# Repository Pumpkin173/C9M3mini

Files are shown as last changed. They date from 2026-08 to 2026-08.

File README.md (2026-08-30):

# C9M3mini 

C9M3mini is a comprehensive open-source camera project, featuring custom hardware (PCBs), 3D printable enclosures, and a C++ based camera application with UI and WiFi sharing capabilities.

## Project Overview
This repository contains everything you need to build the C9M3mini camera from scratch:
- **Software**: A Qt-based C++ application for album viewing, video HUD display, and WiFi sharing.
- **Hardware**: Gerber files and BOMs for custom PCBs (power board, battery board, keypad, etc.).
- **Mechanical**: 3D models (`.3mf`) for 3D printing the camera enclosure.

## Repository Structure
- `/C9M3mini` - The core C++ camera application source code.
- `/C9M3mini_berger` - Hardware manufacturing files. Includes `.zip` Gerber files for PCB fabrication and `.xlsx` Bill of Materials (BOM).
- `C9M3mini_modle.3mf` - 3D printable model for the camera housing (Bambu Studio compatible).

## Software Features
- **Album Viewer**: View captured photos directly on the device.
- **Video HUD**: Heads-Up Display for real-time video recording and monitoring.
- **WiFi Share & Monitor**: Generate QR codes to connect to a local WiFi hotspot and browse files via SMB. Includes real-time connection and speed monitoring.
- **Autostart Support**: Scripts provided to configure the app to run automatically on boot (optimized for Raspberry Pi).

## Prerequisites & Build Instructions (Software)

### Prerequisites
- CMake (version 3.10 or higher)
- C++ Compiler (GCC, Clang, etc.)
- Qt Framework (for UI components)
- `qrencode` (for generating WiFi sharing QR codes)
- Linux network utilities (`ip`, `iw`) for network monitoring

### Build Steps
1. Clone the repository:
   ```bash
   git clone https://github.com/Pumpkin173/C9M3mini.git
   cd C9M3mini/C9M3mini
2. Build the project using CMake:
   mkdir build && cd build
   cmake ..
   cmake --build .
Autostart Setup
To set up the application to run automatically on startup (e.g., on a Raspberry Pi):
./scripts/setup_autostart.sh
## Authors
[Pumpkin173] (Creator & Hardware/Software Engineer)
antigravity--Gemini (Co-author & Assistant)
## License
This project is licensed under the GNU General Public License v3.0 (GPLv3) - see the 
LICENSE file for details.

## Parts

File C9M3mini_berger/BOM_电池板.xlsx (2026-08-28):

No. | Quantity | Comment | Designator | Footprint | Value | Manufacturer Part | Manufacturer | Supplier Part | Supplier
1 | 2 | 100nF | C13,C14 | C0603 | 100nF | CC0603KRX7R9BB104 | YAGEO(国巨) | C14663 | LCSC
2 | 2 | HJ8205 | Q1,Q2 | SOT-23-6_L2.9-W1.6-P0.95-LS2.8-BR |  | HJ8205 | R+O(宏嘉诚) | C20069150 | LCSC
3 | 2 | 330Ω | R21,R22 | R0603 | 330Ω | 0603WAF3300T5E | UNI-ROYAL(厚声) | C23138 | LCSC
4 | 1 | 2kΩ | R23 | R0603 | 2kΩ | 0603WAF2001T5E | UNI-ROYAL(厚声) | C22975 | LCSC
5 | 1 | KNTC0603/10KF3950 | RNTC0 | R0603 |  | KNTC0603/10KF3950 | KUU | C2892547 | LCSC
6 | 1 | 23E413050 | U1 | SMD_23E413050 |  | 23E413050 | SAMZO(三佐) | C39833033 | LCSC
7 | 1 | HY2120-CB | U12 | SOT-23-6_L2.9-W1.6-P0.95-LS2.8-BR |  | HY2120-CB | HYCON(宏康) | C116509 | LCSC

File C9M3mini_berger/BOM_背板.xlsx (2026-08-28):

No. | Quantity | Comment | Designator | Footprint | Value | Manufacturer Part | Manufacturer | Supplier Part | Supplier
1 | 5 | 10uF | C1,C2,C21,C24,C27 | C1206 | 10uF | CL31A106KAHNNNE | SAMSUNG(三星) | C9807 | LCSC
2 | 10 | 100nF | C3,C4,C10,C11,C12,C13,C15,C20,C25,C26 | C0603 | 100nF | CC0603KRX7R9BB104 | YAGEO(国巨) | C14663 | LCSC
3 | 1 | 10nF | C5 | C0603 | 10nF | 0603B103K500NT | FH(风华) | C57112 | LCSC
4 | 1 | 2.2nF | C6 | C0603 | 2.2nF | 0603B222K500NT | FH(风华) | C1604 | LCSC
5 | 1 | 22pF | C7 | C0603 | 22pF | CL10C220JB8NNNC | SAMSUNG(三星) | C1653 | LCSC
6 | 2 | 47uF | C8,C9 | C1206 | 47uF | CL31A476MPHNNNE | SAMSUNG(三星) | C96123 | LCSC
7 | 1 | 10uF | C14 | C0603 | 10uF | FCC0603X106K100CT | FOJAN(富捷) | C5137565 | LCSC
8 | 1 | 100pF | C23 | C0603 | 100pF | CL10C101JB8NNNC | SAMSUNG(三星) | C14858 | LCSC
9 | 1 | 1uF | C28 | C0805 | 1uF | CL21B105KBFNNNE | SAMSUNG(三星) | C28323 | LCSC
10 | 1 | HC-1.25-2PWT | CN1 | CONN-SMD_2P-P1.25-HC-1.25-2PWT |  | HC-1.25-2PWT | HCTL(华灿天禄) | C2845379 | LCSC
11 | 4 | SS54 | D1,D2,D4,D5 | SMA_L4.3-W2.6-LS5.0-FD |  | SS54 | R+O(宏嘉诚) | C7420369 | LCSC
12 | 1 | SS34 | D3 | SMA_L4.3-W2.6-LS5.2-RD |  | SS34 | MDD(辰达半导体) | C8678 | LCSC
13 | 1 | BSMD1812L-500 | F1 | F1812 |  | BSMD1812L-500 | BHFUSE(佰宏) | C42429411 | LCSC
14 | 1 | FPC-05F-6PH20 | FPC_BACK61 | FPC-SMD_6P-P0.50_XUNPU_FPC-05F-6PH20 |  | FPC-05F-6PH20 | XUNPU(讯普) | C2856796 | LCSC
15 | 1 | AFC01-S16FCA-00 | FPC_FORNT1 | FPC-SMD_P0.50-16P_FGS-XJ-H2.0 |  | AFC01-S16FCA-00 | JS(钜硕电子) | C262665 | LCSC
16 | 1 | AFC01-S10FCA-00 | FPC_TOP1 | FPC-SMD_P0.5-10P_FGS-XJ-H2.0 |  | AFC01-S10FCA-00 | JS(钜硕电子) | C262659 | LCSC
17 | 1 | SLO0520H100MTT | L2 | IND-SMD_L5.4-W5.1 |  | SLO0520H100MTT | Sunltech(顺磁) | C325986 | LCSC
18 | 1 | AFC07-S22ECC-00 | P5 | FPC-SMD_P0.50-22P_LSSJ-H2.0-22P |  | AFC07-S22ECC-00 | JS(钜硕电子) | C11091 | LCSC
19 | 1 | 150kΩ | R1 | R0603 | 150kΩ | FRC0603F1503TS | FOJAN(富捷) | C2906993 | LCSC
20 | 1 | 39kΩ | R2 | R0603 | 39kΩ | 0603WAF3902T5E | UNI-ROYAL(厚声) | C23153 | LCSC
21 | 1 | 37.4kΩ | R3 | R0603 | 37.4kΩ | RMC060337.4K1%N | Tyohm(幸亚电阻) | C325691 | LCSC
22 | 1 | 49.9Ω | R4 | R0603 | 49.9Ω | 0603WAF499JT5E | UNI-ROYAL(厚声) | C23185 | LCSC
23 | 1 | 22kΩ | R5 | R0603 | 22kΩ | 0603WAF2202T5E | UNI-ROYAL(厚声) | C31850 | LCSC
24 | 1 | 3.9kΩ | R6 | R0603 | 3.9kΩ | 0603WAF3901T5E | UNI-ROYAL(厚声) | C23018 | LCSC
25 | 1 | 4.7kΩ | R11 | R0603 | 4.7kΩ | 0603WAF4701T5E | UNI-ROYAL(厚声) | C23162 | LCSC
26 | 1 | 27kΩ | R12 | R0603 | 27kΩ | 0603WAF2702T5E | UNI-ROYAL(厚声) | C22967 | LCSC
27 | 1 | 1kΩ | R13 | R0603 | 1kΩ | 0603WAF1001T5E | UNI-ROYAL(厚声) | C21190 | LCSC
28 | 1 | 50kΩ | R14 | R0603 | 50kΩ | RT0603BRD0750KL | YAGEO(国巨) | C861451 | LCSC
29 | 1 | 3Ω | R15 | R0603 | 3Ω | RCA033RFLF | HKR(香港电阻) | C22356394 | LCSC
30 | 1 | 24kΩ | R16 | R0603 | 24kΩ | 0603WAF2402T5E | UNI-ROYAL(厚声) | C23352 | LCSC
31 | 2 | 10Ω | RFILTER0,RFILTER1 | R0603 | 10Ω | 0603WAF100JT5E | UNI-ROYAL(厚声) | C22859 | LCSC
32 | 1 | 100kΩ | RGAIN_SLOT0 | R0603 | 100kΩ | FRC0603F1003TS | FOJAN(富捷) | C2906980 | LCSC
33 | 2 | 400mΩ | Rin1,Rin2 | R1206 | 400mΩ | 1206W4F400LT5E | UNI-ROYAL(厚声) | C247521 | LCSC
34 | 1 | 100mΩ | Rs0 | R1210 | 100mΩ | 1210W2F100LT5E | UNI-ROYAL(厚声) | C270892 | LCSC
35 | 1 | 10mΩ | RSHUNT0 | R2512 | 10mΩ | RE2512F3R010 | JIERR(捷而瑞) | C46961753 | LCSC
36 | 1 | KT-0603R | R_LED3 | LED-SMD_L1.6-W0.8-R-RD |  | KT-0603R | KENTO | C2286 | LCSC
37 | 1 | 820kΩ | single1 | R0603 | 820kΩ | FRC0603F8203TS | FOJAN(富捷) | C2907070 | LCSC
38 | 1 | TYPE-C 16PIN 2MD(073) | Type_C0 | USB-C-SMD_TYPE-C-16PIN-2MD-073 |  | TYPE-C 16PIN 2MD(073) | SHOU HAN(首韩) | C2765186 | LCSC
39 | 1 | 4.7uH | U1 | IND-SMD_L7.2-W6.6_GPSR07X0 | 4.7uH | CYA0630-4.7UH | SHOU HAN(首韩) | C5189748 | LCSC
40 | 1 | MAX98357AETE+T | U3 | TQFN-16_L3.0-W3.0-P0.50-BL-EP1.5 |  | MAX98357AETE+T | ADI(亚德诺)/MAXIM(美信) | C910544 | LCSC
41 | 1 | 2.54-2*20 | U4 | HDR-TH_40P-P2.54-V-F-R2-C20-S2.54 |  | 2.54-2*20 | ZHOURI(洲日) | C2977589 | LCSC
42 | 1 | CH224A | U10 | ESSOP-10_L4.9-W3.9-P1.0-LS6.0-TL-EP |  | CH224A | WCH(南京沁恒) | C42459160 | LCSC
43 | 1 | TPS54531DDAR | U13 | SOIC-8_L5.0-W4.0-P1.27-LS6.0-BL-EP2.0 |  | TPS54531DDAR | TI(德州仪器) | C50605 | LCSC
44 | 1 | TP5100 | U15 | TQFN-16_L4.0-W4.0-P0.65-BL-EP |  | TP5100 | TOPPOWER(南京拓微) | C379389 | LCSC
45 | 1 | INA226AIDGSR | U17 | MSOP-10_L3.0-W3.0-P0.50-LS5.0-BL |  | INA226AIDGSR | TI(德州仪器) | C49851 | LCSC
46 | 1 | ZX-PM2.54-1-2PY | U18 | HDR-TH_2P-P2.54-V-F |  | ZX-PM2.54-1-2PY | Megastar(兆星) | C7499322 | LCSC

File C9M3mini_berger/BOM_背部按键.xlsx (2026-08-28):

No. | Quantity | Comment | Designator | Footprint | Value | Manufacturer Part | Manufacturer | Supplier Part | Supplier
1 | 1 | HC-FPC-05-09-4RLTAG | FPC_BACK4 | FPC-SMD_4P-P0.50_HC-FPC-05-09-4RLTAG |  | HC-FPC-05-09-4RLTAG | HCTL(华灿天禄) | C5213746 | LCSC
2 | 1 | FPC-05F-6PH20 | FPC_BACK6 | FPC-SMD_6P-P0.50_XUNPU_FPC-05F-6PH20 |  | FPC-05F-6PH20 | XUNPU(讯普) | C2856796 | LCSC
3 | 4 | TS-1088-AR02016 | SW1,SW2,SW3,SW4 | SW-SMD_L3.9-W3.0-P4.45 |  | TS-1088-AR02016 | XUNPU(讯普) | C720477 | LCSC
4 | 1 | SKRHABE010 | SW9 | SW-SMD_SKRHABE010 |  | SKRHABE010 | ALPSALPINE(阿尔卑斯阿尔派) | C139794 | LCSC

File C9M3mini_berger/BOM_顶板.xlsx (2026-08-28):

No. | Quantity | Comment | Designator | Footprint | Value | Manufacturer Part | Manufacturer | Supplier Part | Supplier
1 | 4 | 100nF | C31,C32,C33,C34 | C0603 | 100nF | CGA0603X7R104K500JT | HRE(芯声) | C6119867 | LCSC
2 | 1 | H5VL10B | D1 | SOD-882_L1.0-W0.6-BI |  | H5VL10B | R+O(宏嘉诚) | C7420372 | LCSC
3 | 2 | BWCD-L3.5W2.0H1.0 | FLASH_CENTER1,FLASH_SIDE1 | SMD_BD2.0-L2.0-W2.0_C9900001905 |  | BWCD-L3.5W2.0H1.0 | BAT WIRELESS(蝙蝠无线) | C2826547 | LCSC
4 | 1 | HC-FPC-05-09-4RLTAG | FPC_BACK41 | FPC-SMD_4P-P0.50_HC-FPC-05-09-4RLTAG |  | HC-FPC-05-09-4RLTAG | HCTL(华灿天禄) | C5213746 | LCSC
5 | 1 | AFC01-S10FCA-00 | FPC_TOP1 | FPC-SMD_P0.5-10P_FGS-XJ-H2.0 |  | AFC01-S10FCA-00 | JS(钜硕电子) | C262659 | LCSC
6 | 1 | PZ254V-11-01P | H1 | HDR-TH_1P-P2.54-V-M |  | PZ254V-11-01P | XFCN(兴飞) | C492400 | LCSC
7 | 1 | EC11E09244BS | MODE1 | SW-TH_EC11XXXXXXXX |  | EC11E09244BS | ALPSALPINE(阿尔卑斯阿尔派) | C470742 | LCSC
8 | 4 | TS-1088-AR02016 | ON_OFF_0,REC0,SW6,SW7 | SW-SMD_L3.9-W3.0-P4.45 |  | TS-1088-AR02016 | XUNPU(讯普) | C720477 | LCSC
9 | 1 | AFC07-S22ECC-00 | P5 | FPC-SMD_P0.50-22P_LSSJ-H2.0-22P |  | AFC07-S22ECC-00 | JS(钜硕电子) | C11091 | LCSC
10 | 1 | 2N7002K-T1-GE3 | Q1 | SOT-23-3_L2.9-W1.6-P1.90-LS2.8-BR |  | 2N7002K-T1-GE3 | VISHAY(威世) | C81445 | LCSC
11 | 3 | 100Ω | R1,R30,R31 | R0603 | 100Ω | FRC0603F1000TS | FOJAN(富捷) | C2906981 | LCSC
12 | 16 | 10kΩ | R37,R310,R311,R312,R313,R314,R315,R316,R317,R318,R319,R320,R321,R322,R323,R324 | R0603 | 10kΩ | FRC0603J103 TS | FOJAN(富捷) | C2930027 | LCSC
13 | 1 | MSK12C02 | SW0 | SW-TH_MSK12C02 |  | MSK12C02 | SHOU HAN(首韩) | C431540 | LCSC
14 | 2 | KT-0603R | TALLY0,TALLY1 | LED-SMD_L1.6-W0.8-R-RD |  | KT-0603R | KENTO | C2286 | LCSC
15 | 1 | GT-BTP20003-0280A-009A | U1 | CONN-TH_GT-BTP20003-0280A-009A |  | GT-BTP20003-0280A-009A | G-Switch(品赞) | C29780050 | LCSC
16 | 1 | SKAR-10S | U2 | SW-SMD_SKAR-10S |  | SKAR-10S | SM Switch | C2841466 | LCSC
17 | 1 | AW9523BTQR | U18 | VFQFPN-24_L4.0-W4.0-P0.50-BL-EP2.8 |  | AW9523BTQR | AWINIC(艾为) | C148077 | LCSC

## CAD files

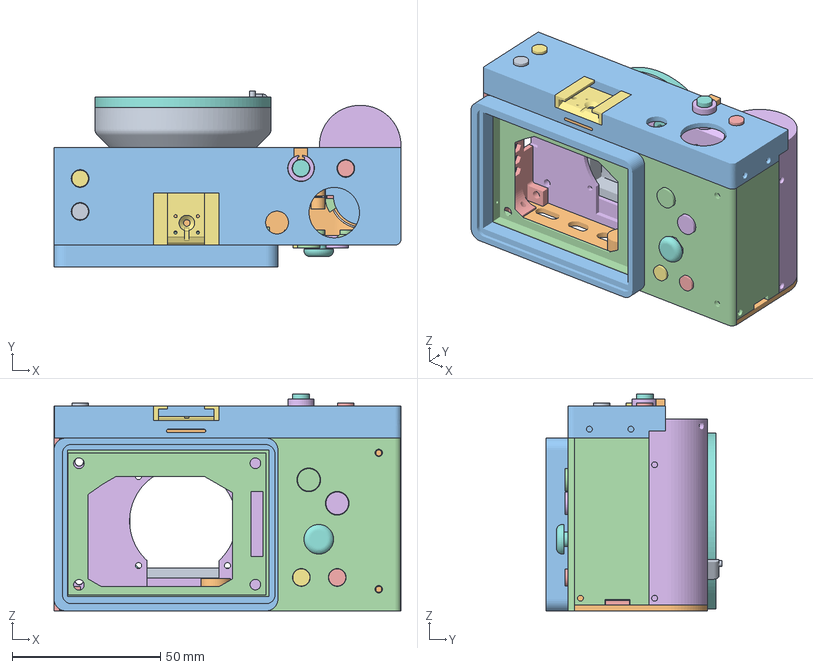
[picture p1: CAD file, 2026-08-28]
C9M3mini_modle.3mf
117.0 x 59.3 x 73.1 mm
E卡口
实体1 x 9
实体2 x 2
实体3
实体39
实体4
实体40
实体41
实体42
实体44
实体5
实体53
实体59
实体6
实体60
实体61
实体62
实体69
实体7
实体70
实体71
实体72
实体73
实体84

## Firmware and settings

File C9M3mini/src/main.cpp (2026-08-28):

#include <QApplication>
#include <cstdlib>
#include <qglobal.h>
#include <QFile>
#include "ui/MainWindow.h"

int main(int argc, char* argv[]) {
    if (qEnvironmentVariableIsEmpty("WAYLAND_DISPLAY") && qEnvironmentVariableIsEmpty("DISPLAY")) {
        const char* xdgDir = qgetenv("XDG_RUNTIME_DIR").constData();
        QByteArray wl1 = QByteArray(xdgDir) + "/wayland-1";
        QByteArray wl0 = QByteArray(xdgDir) + "/wayland-0";

        if (QFile::exists(QString::fromLocal8Bit(wl1))) {
            qputenv("WAYLAND_DISPLAY", "wayland-1");
            qputenv("QT_QPA_PLATFORM", "wayland");
        } else if (QFile::exists(QString::fromLocal8Bit(wl0))) {
            qputenv("WAYLAND_DISPLAY", "wayland-0");
            qputenv("QT_QPA_PLATFORM", "wayland");
        } else {
            qputenv("QT_QPA_PLATFORM", "eglfs");
            qputenv("QT_QPA_EGLFS_ROTATION", "90");
            qputenv("QT_QPA_EGLFS_ALWAYS_SET_MODE", "1");
            // 锁定字体 DPI，防止 EGLFS 下字体因无法读取屏幕 EDID 而被异常放大
            qputenv("QT_FONT_DPI", "85");
            qputenv("QT_QPA_EGLFS_NO_LIBINPUT", "1");
            qputenv("QT_QPA_EVDEV_TOUCHSCREEN_PARAMETERS", "rotate=90");
        }
    }

    QApplication app(argc, argv);
    MainWindow w;
    w.showFullScreen();

    return app.exec();
}

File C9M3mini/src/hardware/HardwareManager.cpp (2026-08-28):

#include "HardwareManager.h"
#include <QDebug>
#include <fcntl.h>
#include <unistd.h>
#include <sys/ioctl.h>
#include <linux/i2c-dev.h>
#include <errno.h>
#include <cstring>
#include <linux/gpio.h>

#ifndef GPIOHANDLE_REQUEST_BIAS_PULL_UP
#define GPIOHANDLE_REQUEST_BIAS_PULL_UP (1UL << 5)
#endif

// AW9523 寄存器定义
#define AW9523_REG_INPUT0     0x00
#define AW9523_REG_INPUT1     0x01  // P1 Input Port
#define AW9523_REG_OUTPUT1    0x03  // P1 Output Port
#define AW9523_REG_CONFIG0    0x04  // P0 Config
#define AW9523_REG_CONFIG1    0x05  // P1 Config (0=Output, 1=Input)
#define AW9523_REG_LEDMODE_P1 0x13  // P1 LED/GPIO Mode (0=LED, 1=GPIO)
#define AW9523_REG_SW_RSTN    0x7F  // Software Reset
#define AW9523_REG_CHIP_ID    0x10  // ID Register (Read only, should be 0x23)

// AD0=GND, AD1=GND -> Address is 0x58
#define AW9523_ADDR           0x58

HardwareManager::HardwareManager(QObject* parent) : QThread(parent) {
    stopFlag = false;
}

HardwareManager::~HardwareManager() {
    stop();
    wait();
}

void HardwareManager::stop() {
    stopFlag = true;
}

void HardwareManager::setTallyLed(bool turnOn) {
    m_tallyLedState = turnOn;
    m_tallyLedUpdatePending = true;
}

void HardwareManager::run() {
    qDebug() << "Hardware: Thread starting...";

    // 初始化 I2C (AW9523)
    int fd = open("/dev/i2c-1", O_RDWR);
    if (fd < 0 || ioctl(fd, I2C_SLAVE, AW9523_ADDR) < 0) {
        qDebug() << "Hardware: I2C init failed.";
        if (fd >= 0) close(fd);
        return;
    }

    // 复位并设置 P1 为 GPIO 模式
    i2cWriteByte(fd, AW9523_REG_SW_RSTN, 0x00);
    usleep(50000); // 加长等待确保复位完成 (50ms)
    i2cWriteByte(fd, AW9523_REG_LEDMODE_P1, 0xFF); // P1 全部设为 GPIO 模式

    // 默认关闭 Tally LED (P1_0 拉高，因为发光二极管阴极接在 P1_0)
    i2cWriteByte(fd, AW9523_REG_OUTPUT1, 0x01); // 保证 P1_0 输出高电平

    // 确认 LEDMODE 写入成功
    unsigned char ledmode = 0;
    i2cReadByte(fd, AW9523_REG_LEDMODE_P1, ledmode);
    qDebug() << "Hardware: AW9523 P1 LEDMODE register =" << Qt::hex << (int)ledmode
             << "(expected: 0xFF = all GPIO mode)";

    // 配置引脚输入输出
    unsigned char cfg0 = 0, cfg1 = 0;
    i2cReadByte(fd, AW9523_REG_CONFIG0, cfg0);
    i2cReadByte(fd, AW9523_REG_CONFIG1, cfg1);

    cfg0 |= 0x80; // P0_7 配置为输入 (拍照/视频切换)
    cfg0 |= 0x20; // P0_5 配置为输入 (相册按钮)
    cfg0 |= 0x10; // P0_4 配置为输入 (del 按键)
    cfg0 |= 0x40; // P0_6 配置为输入 (Fn 键，用于退出播放)
    cfg0 |= 0x0F; // P0_0~P0_3 配置为输入 (档位转盘，公共端接GND)

    cfg1 &= ~0x01; // P1_0 配置为输出 (Tally LED)
    cfg1 |= 0x0E;  // P1_1(E), P1_2(B), P1_3(A) 配置为输入 (EC11)
    cfg1 |= 0x10;  // P1_4 配置为输入 (Menu 键)
    cfg1 |= 0x20; // P1_5 配置为输入 (快门)
    cfg1 |= 0x80; // P1_7 配置为输入 (录制按键 1)

    i2cWriteByte(fd, AW9523_REG_CONFIG0, cfg0);
    i2cWriteByte(fd, AW9523_REG_CONFIG1, cfg1);
    qDebug() << "Hardware: AW9523 CONFIG0 =" << Qt::hex << (int)cfg0
             << "| CONFIG1 =" << Qt::hex << (int)cfg1;

    // 初始化 GPIO
    int gpio_fd = open("/dev/gpiochip4", O_RDWR);
    int line_fd_25 = -1;
    if (gpio_fd >= 0) {
        struct gpiohandle_request req;
        memset(&req, 0, sizeof(req));
        req.lineoffsets[0] = 25;
        req.flags = GPIOHANDLE_REQUEST_INPUT | GPIOHANDLE_REQUEST_BIAS_PULL_UP;
        req.lines = 1;
        strcpy(req.consumer_label, "video_rec_redundant");
        if (ioctl(gpio_fd, GPIO_GET_LINEHANDLE_IOCTL, &req) == 0) {
            line_fd_25 = req.fd;
            qDebug() << "Hardware: GPIO 25 initialized for redundant trigger.";
        } else {
            qDebug() << "Hardware: Request input failed.";
        }
    } else {
        qDebug() << "Hardware: Failed to open gpiochip4. Redundant trigger offline.";
    }

    auto requestJoystickPin = [&](int offset, const char* label) -> int {
        if (gpio_fd < 0) return -1;
        struct gpiohandle_request req;
        memset(&req, 0, sizeof(req));
        req.lineoffsets[0] = offset;
        req.flags = GPIOHANDLE_REQUEST_INPUT | GPIOHANDLE_REQUEST_BIAS_PULL_UP;
        req.lines = 1;
        strcpy(req.consumer_label, label);
        if (ioctl(gpio_fd, GPIO_GET_LINEHANDLE_IOCTL, &req) == 0) {
            qDebug() << "Hardware: GPIO" << offset << "initialized for" << label;
            return req.fd;
        }
        return -1;
    };

    int line_fd_16 = requestJoystickPin(16, "joystick_center");
    int line_fd_5  = requestJoystickPin(5,  "joystick_left");
    int line_fd_6  = requestJoystickPin(6,  "joystick_down");
    int line_fd_22 = requestJoystickPin(22, "joystick_up");
    int line_fd_26 = requestJoystickPin(26, "joystick_right");

    // 闪光灯与硬件触发引脚 (GPIO 17, 23) 已移交 PioTriggerController
    // m_flashLineFd = -1;
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

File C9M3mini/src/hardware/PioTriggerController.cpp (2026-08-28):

#include "PioTriggerController.h"
#include <QDebug>
#include <QCoreApplication>
#include <chrono>
#include <thread>
#include <ctime>

#include <fcntl.h>
#include <unistd.h>
#include <sys/ioctl.h>
#include <cerrno>
#include <cstring>

#include "piolib.h"
#include "imx296_trigger.pio.h"

#define PIN_XTR   17    // XTR Trigger
#define PIN_FLASH 23    // Flash

// 构造 / 析构
PioTriggerController::PioTriggerController(QObject* parent)
    : QThread(parent)
    , m_pio(nullptr)
    , m_sm_trigger(-1)
    , m_offset_trigger(0)
    , m_running(false)
    , m_previewFps(30)
    , m_previewExposureUs(5000)
{}

PioTriggerController::~PioTriggerController() {
    stopPreview();
    wait();

    if (m_pio) {
        if (m_sm_trigger >= 0) { 
            pio_sm_set_enabled(m_pio, m_sm_trigger, false); 
            pio_sm_unclaim(m_pio, m_sm_trigger); 
        }
        pio_close(m_pio);
    }
}

bool PioTriggerController::init() {
    qInfo() << "PioTrigger: Initializing for Raspberry Pi 5...";
    m_pio = pio_open(0);
    
    if (!m_pio || PIO_IS_ERR(m_pio)) {
        qCritical() << "PioTrigger: Failed to open RP1 PIO 0!";
        return false;
    }

    // 关闭 SM0
    pio_set_sm_mask_enabled(m_pio, 0x1, false);

    // 认领 SM0
    pio_sm_claim(m_pio, 0);
    m_sm_trigger = 0;
    
    // 清空指令内存
    errno = 0;
    pio_clear_instruction_memory(m_pio);
    qDebug() << "PioTrigger: Clear instruction memory completed. True errno:" << errno << strerror(errno);
    
    usleep(50000); // 等待 50ms 确保硬件清理完毕，防止总线繁忙导致超时

    errno = 0;
    int offset = (int)pio_add_program(m_pio, &camera_trigger_program);
    if (offset < 0) {
        qWarning() << "PioTrigger: camera_trigger add failed! errno:" << errno << strerror(errno);
        return false;
    } else {
        m_offset_trigger = offset;
        qDebug() << "PioTrigger: camera_trigger dynamically loaded at offset=" << m_offset_trigger;
    }

    // 配置 Trigger SM (统一控制 XTR 和 FLASH)
    pio_sm_config c = camera_trigger_program_get_default_config(m_offset_trigger);
    
    // XTR 控制: 使用 set pins (GPIO 17)
    sm_config_set_set_pins(&c, PIN_XTR, 1);
    // FLASH 控制: 使用 sideset pins (GPIO 23)
    sm_config_set_sideset_pins(&c, PIN_FLASH);
    
    sm_config_set_clkdiv(&c, 200.0f); // RP1 sys_clk 200MHz / 200.0 = 1MHz -> 1 cycle = 1us

    // 初始化 GPIO 引脚
    pio_gpio_init(m_pio, PIN_XTR);
    pio_gpio_init(m_pio, PIN_FLASH);
    
    // 设置引脚的初始状态 (XTR=HIGH, FLASH=LOW)
    pio_sm_set_pins_with_mask(m_pio, m_sm_trigger, 1u << PIN_XTR, (1u << PIN_XTR) | (1u << PIN_FLASH));
    
    // 配置引脚方向为输出
    pio_sm_set_consecutive_pindirs(m_pio, m_sm_trigger, PIN_XTR, 1, true);
    pio_sm_set_consecutive_pindirs(m_pio, m_sm_trigger, PIN_FLASH, 1, true);
    
    // 初始化状态机
    pio_sm_init(m_pio, m_sm_trigger, m_offset_trigger, &c);

    // 启动状态机
    pio_sm_set_enabled(m_pio, m_sm_trigger, true);

    qDebug() << "PioTrigger: Unified Trigger SM running.";
    return true;
}

void PioTriggerController::startPreview(int fps, int exposureUs) {
    m_previewFps        = fps;
    m_previewExposureUs = exposureUs;
    if (!m_running) {
        m_running = true;
        start();
    }
}

void PioTriggerController::stopPreview() {
    m_running = false;
}

void PioTriggerController::run() {
    qDebug() << "PioTrigger: Preview thread started at" << m_previewFps << "fps.";

    while (m_running) {
        std::lock_guard<std::mutex> lock(m_fifoMutex);
        
        // 动态计算当前需要的硬件帧周期 (Frame Interval)
        uint32_t frameIntervalUs = 1000000 / m_previewFps.load();
        
        if (m_captureRequested.load()) {
            // 无缝插入闪光拍摄帧
            if (m_preFireCallback) {
                m_preFireCallback();
            }
            
            uint32_t exposureUs = m_captureExposureUs.load();
            uint32_t offsetUs = m_captureFlashDelayUs.load();
            
            // 强制脉宽 >= 15us，避免同步错位
            uint32_t pioExposureUs = (exposureUs > 29) ? (exposureUs - 14) : 15;
            
            // 保证留白时间 > 0，维持周期稳定。拍摄模式下总耗时 = offsetUs + pioExposureUs + blankingUs
            uint32_t totalActive = pioExposureUs + offsetUs;
            uint32_t blankingUs = (frameIntervalUs > totalActive) ? (frameIntervalUs - totalActive) : 100;

            qDebug() << "PioTrigger: Seamless Capture Pulse! Target Exp:" << exposureUs 
                     << "us | PIO Pulse:" << pioExposureUs 
                     << "us | Flash pre-delay:" << offsetUs << "us | Blanking:" << blankingUs << "us";

            // 非阻塞入队，避免触发底层 PIO 驱动 put 操作超时
            auto safe_pio_put = [&](uint32_t data) {
                while (pio_sm_is_tx_fifo_full(m_pio, m_sm_trigger)) {
                    std::this_thread::sleep_for(std::chrono::milliseconds(2));
                }
                pio_sm_put(m_pio, m_sm_trigger, data);
            };

            // 推送参数: [mode=1] [offsetUs-1] [pioExposureUs-1] [blankingUs-1]
            safe_pio_put(1u);
            safe_pio_put(std::max(1u, offsetUs) - 1);
            safe_pio_put(std::max(1u, pioExposureUs) - 1);
            safe_pio_put(std::max(1u, blankingUs) - 1);

            // 等待物理曝光完成
            // 轮询等待曝光完成，避免内核驱动超时
            while (pio_sm_is_rx_fifo_empty(m_pio, m_sm_trigger)) {
                std::this_thread::sleep_for(std::chrono::milliseconds(2));
            }
            pio_sm_get(m_pio, m_sm_trigger);
            
            // 记录曝光结束时间戳
            struct timespec _ts;
            clock_gettime(CLOCK_BOOTTIME, &_ts);
            m_lastFireTimestampNs.store(
                (int64_t)_ts.tv_sec * 1000000000LL + (int64_t)_ts.tv_nsec,
                std::memory_order_release);
            
            // 硬件确认曝光完成，通知 MainWindow 可以停止看门狗
            emit exposureCompleted();
            
            m_captureRequested = false;
        } else {
            // 预览模式
            uint32_t exposureUs = static_cast<uint32_t>(m_previewExposureUs.load());
            
            // 核心公式补偿：Pulse Width = Target Exposure - 14.26us (取整 14us)，保底 15us 以免丢帧
            uint32_t pioExposureUs = (exposureUs > 29) ? (exposureUs - 14) : 15;
            
            // 设定最小 100us Blanking，确保全局快门数据完整读出
            if (pioExposureUs + 100 >= frameIntervalUs) {
                pioExposureUs = frameIntervalUs - 100;
            }
            uint32_t blankingUs = frameIntervalUs - pioExposureUs;

            // 非阻塞入队，避免触发底层 PIO 驱动 put 操作超时
            auto safe_pio_put = [&](uint32_t data) {
                while (pio_sm_is_tx_fifo_full(m_pio, m_sm_trigger)) {
                    std::this_thread::sleep_for(std::chrono::milliseconds(2));
                }
                pio_sm_put(m_pio, m_sm_trigger, data);
            };

            // 推送参数: [mode=0] [pioExposureUs-1] [blankingUs-1]
            safe_pio_put(0u);
            safe_pio_put(std::max(1u, pioExposureUs) - 1);
            safe_pio_put(std::max(1u, blankingUs) - 1);
            
            // 预览模式无 push block，禁止调用 get_blocking
        }
    }
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
